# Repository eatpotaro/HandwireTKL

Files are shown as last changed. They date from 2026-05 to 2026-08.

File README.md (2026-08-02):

# Handwiring a TKL Keyboard to replace my old one!
see project on macondo here   
(https://macondo.hackclub.com/projects/15845)

# Features
Full ISO TKL Layout  
1 Rotary Encoders    
128x32 OLED Display  
No PCB needed!  

# How to use
3D print bottom plate, risers, and top plate, or case and top plate
Handwire all switches and microcontroller according to design
Install circuitpython and KMK on microcontroller by dragging .uf2 file when in boot mode   
Install the software (ball.bmp, boid.py, and main.py all in the root directory)

# Firmware Installation Instructions
Assuming you are using the CPico RP2040 as in the build, download this file  
https://circuitpython.org/board/raspberry_pi_pico/   
Then, drag the .uf2 into the microcontroller when it is in boot mode. After that install KMK from here  
https://github.com/KMKfw/kmk_firmware/archive/refs/heads/main.zip    
finally, drag in ball.bmp, boid.py, and main.py into the root directory of the microcontroller.        
See the KMK getting started guide here https://github.com/KMKfw/kmk_firmware/blob/main/docs/en/Getting_Started.md

# Firmware Build Instructions
Since this runs on KMK, there is no need to compile or build the firmware.    
Setup the device as per the README and it will work correctly 

# CAD files
This contains multiple CAD files
- 3D printed plate

- 3D printed case

- 3D printed keycaps

- Milled aluminium case


# Pictures
Layout

Wiring








# Bill of Materials
| Component | Quantity | Total Price (£) | Link |
|---|---|---|---|
| CPico RP2040 | 1 | 6.50 | https://thepihut.com/products/cpico-rp2040?variant=54040618369409 |
| Gazzew Black Boba U4 | 9 | 58.50 | https://www.mechmods.co.uk/collections/keyboard-switches/products/gazzew-black-boba-u4?variant=43956181401823 |
| Durock V3 Stabilisers | 1 set | 15.00 | https://www.mechmods.co.uk/collections/keyboard-stabilisers/products/durock-screw-in-stabilisers-v3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 |
| 20-pin 0.1" Female Header (White, 5-pack) | 1 | 2.20 | https://thepihut.com/products/20-pin-0-1-female-header-white-5-pack?variant=19932895346750 |
| Short Plug Headers for Raspberry Pi Pico (2 × 20 Pin Male) | 1 | 1.00 | https://thepihut.com/products/short-plug-headers-for-raspberry-pi-pico-2-x-20-pin-male |
| TH Diode 1N4148TR | 85 | 2.55 | https://mechboards.co.uk/products/kit-components-and-parts?variant=55527711277436 |
| 128×32 I2C OLED Graphic Display | 1 | 4.00 | https://mechboards.co.uk/products/oled-screen?_pos=3&_sid=27145306e&_ss=r |
| 8mm M2 Screws | 24 | 0.72 | https://mechboards.co.uk/products/kit-components-and-parts?variant=55527712784764 |
| 12mm M2 Brass Standoff | 12 | 0.36 | https://mechboards.co.uk/products/kit-components-and-parts?variant=55527713014140 |
| PEC11-4215F-S24 Rotary Encoder | 1 | 4.40 | https://thepihut.com/products/rotary-encoder-extras |
| Solid Core Wire | - | - | - |
| Solder | - | - | - |
| 3D Printed Plate, Keycaps, Case | - | - | - |
| Milled Aluminium Case* | - | - | - |

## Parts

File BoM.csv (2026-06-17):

Component | Quantity | Total Price (œ) | Link
CPico RP2040 | 1 | 6.5 | https://thepihut.com/products/cpico-rp2040?variant=54040618369409
Gazzew Black Boba U4 | 9 | 58.5 | https://www.mechmods.co.uk/collections/keyboard-switches/products/gazzew-black-boba-u4?variant=43956181401823
Durock V3 Stabilisers | 1 set | 15 | https://www.mechmods.co.uk/collections/keyboard-stabilisers/products/durock-screw-in-stabilisers-v3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
20-pin 0.1" Female Header - White - 5 pack | 1 | 2.2 | https://thepihut.com/products/20-pin-0-1-female-header-white-5-pack?variant=19932895346750
Short Plug Headers for Raspberry Pi Pico - 2 x 20 Pin Male | 1 | 1 | https://thepihut.com/products/short-plug-headers-for-raspberry-pi-pico-2-x-20-pin-male
TH Diode 1N4148TR | 85 | 2.55 | https://mechboards.co.uk/products/kit-components-and-parts?variant=55527711277436
128ž32 I2C OLED graphic display | 1 | 4 | https://mechboards.co.uk/products/oled-screen?_pos=3&_sid=27145306e&_ss=r
8mm M2 Screws | 24 | 0.72 | https://mechboards.co.uk/products/kit-components-and-parts?variant=55527712784764
12mm M2 Brass Standoff | 12 | 0.36 | https://mechboards.co.uk/products/kit-components-and-parts?variant=55527713014140
PEC11-4215F-S24 Rotary Encoder | 1 | 4.4 | https://thepihut.com/products/rotary-encoder-extras
Solid Core Wire | - | - | -
Solder | - | - | -
3D Printed Plate, Keycaps, Case | - | - | -
Milled Aluminium Case* | - | - | -

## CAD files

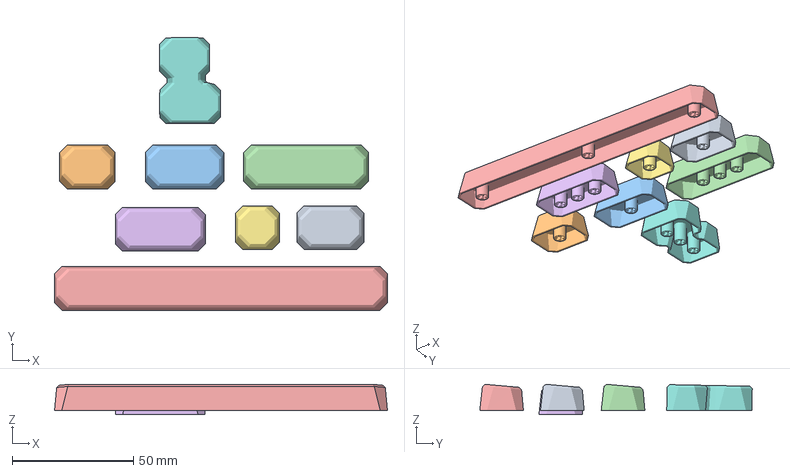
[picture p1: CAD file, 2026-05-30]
3DModel/allKeycaps.3mf
137.1 x 112.2 x 12.5 mm
keycap (1) x 3
keycap (2) x 2
keycap (3) (11)
keycap
keycap

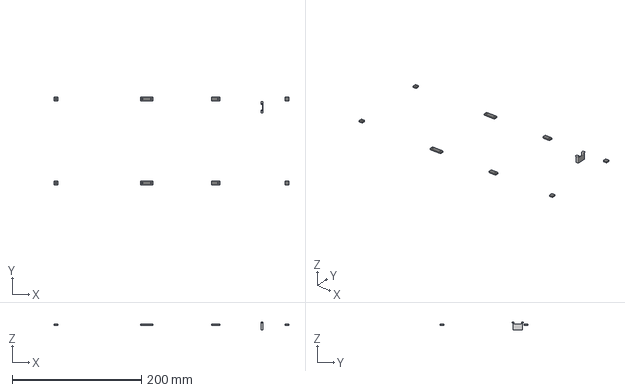
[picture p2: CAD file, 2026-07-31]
3DModel/Step/Risers.step
363.2 x 135.7 x 12.0 mm

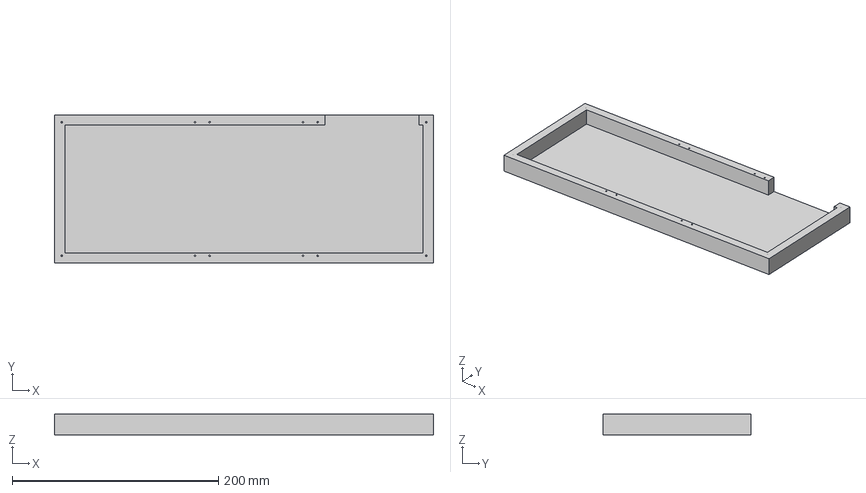
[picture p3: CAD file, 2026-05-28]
3DModel/AluCase.3mf
367.7 x 143.8 x 20.0 mm

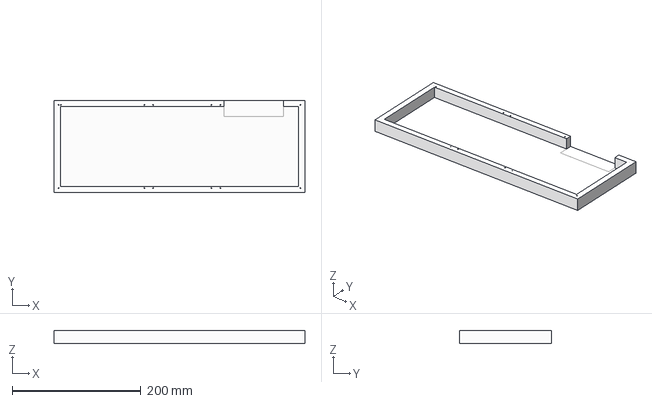
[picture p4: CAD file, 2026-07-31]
3DModel/Step/Case.step
390.4 x 143.8 x 20.0 mm

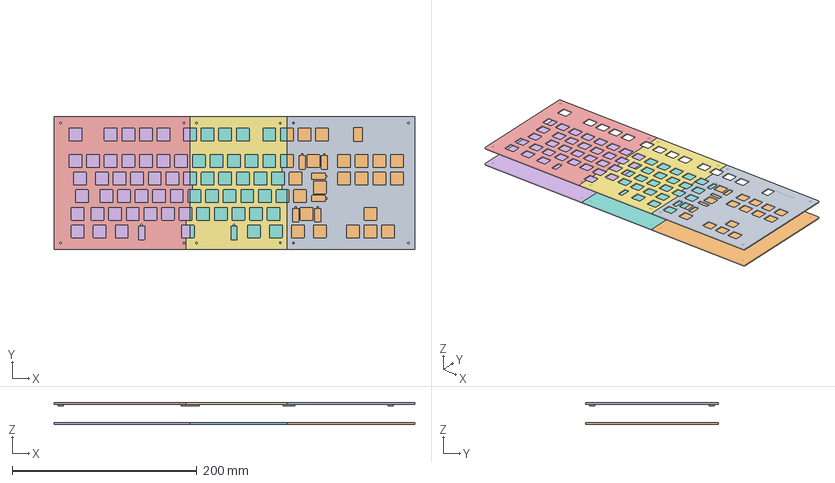
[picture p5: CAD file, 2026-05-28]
3DModel/3DPrintPlateCase.3mf
390.4 x 143.8 x 24.0 mm
corner1
corner2
corner3
corner4
left
leftbottom
middle
middlebottom
right
rightbottom
riser1
riser2
riser3
riser4

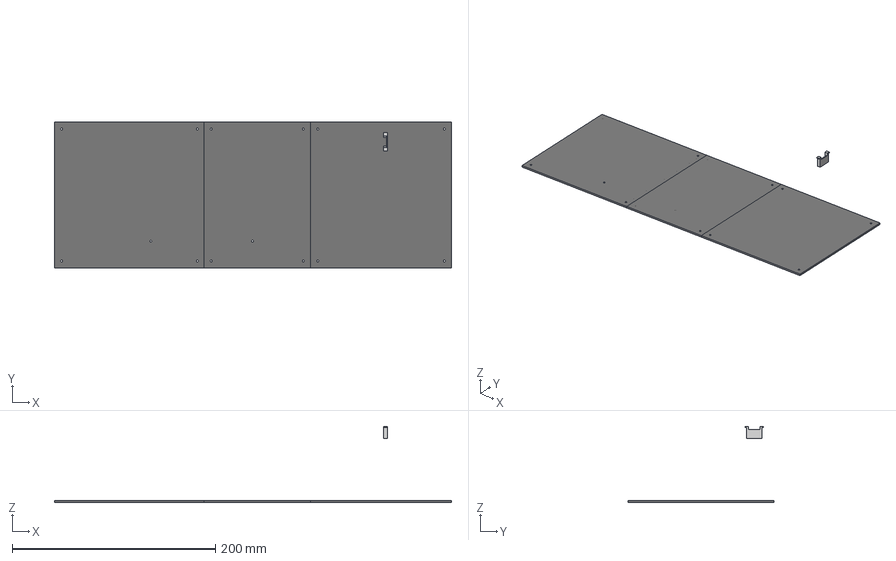
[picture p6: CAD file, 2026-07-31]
3DModel/Step/BottomPlate.step
390.4 x 143.8 x 75.0 mm

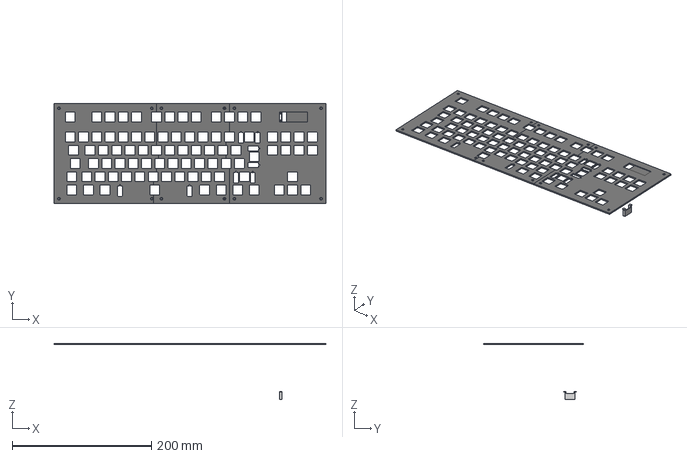
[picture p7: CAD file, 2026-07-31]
3DModel/Step/Plate.step
390.4 x 143.8 x 81.0 mm

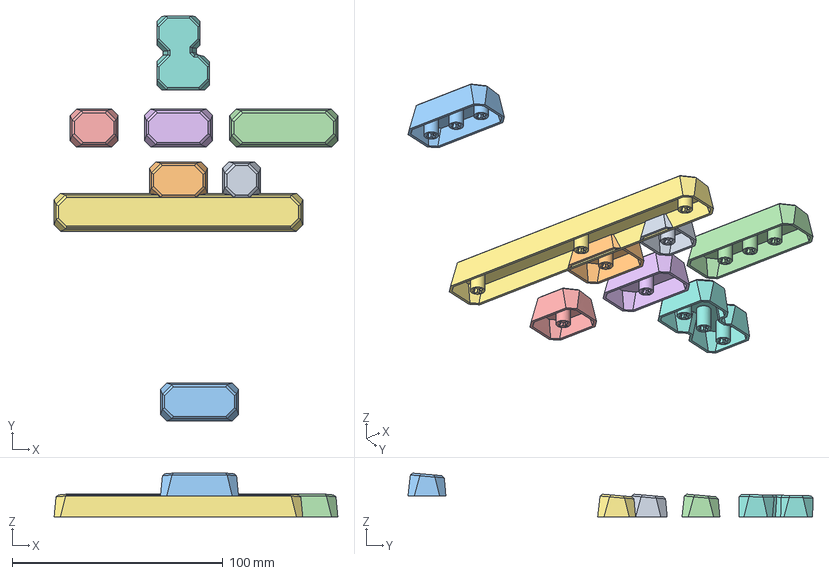
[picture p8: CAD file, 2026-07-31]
3DModel/Step/Keycaps.step
134.7 x 192.2 x 20.8 mm
1Key
1.5key
2key
1.25key
1.75key
6.25key
iso

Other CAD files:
3DModel/AluCase.stl
3DModel/FusionProjectAllParts.f3d

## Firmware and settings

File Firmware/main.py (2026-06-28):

#show starting of device
print("Hello World!")

#import libraries
import board

from kmk.kmk_keyboard import KMKKeyboard
from kmk.keys import KC
from kmk.scanners import DiodeOrientation
from kmk.keys import Key

from kmk.modules.layers import Layers

from kmk.extensions.international import International
from kmk.modules.encoder import EncoderHandler
from kmk.extensions.media_keys import MediaKeys

import board
import busio

import random

from kmk.extensions.display import Display, TextEntry, ImageEntry

from boid import Ball, Boid

#for display from example
# For SSD1306
from kmk.extensions.display.ssd1306 import SSD1306

# Replace SCL and SDA according to your hardware configuration.
i2c_bus = busio.I2C(board.GP1, board.GP0)

driver = SSD1306(
    # Mandatory:
    i2c=i2c_bus,
)

# setup a new keyboard object with an updateloop
class UpdateKeyboard(KMKKeyboard):
    def __init__(self) -> None:
        super().__init__()
        
    def _main_loop(self) -> None:
        super()._main_loop()
        updateDisplay()
        
keyboard = UpdateKeyboard()

#add extras
keyboard.extensions.append(International())
keyboard.extensions.append(MediaKeys())
layers = Layers()
keyboard.modules.append(layers)

#setup encoder
encoder_handler = EncoderHandler()
encoder_handler.pins = ((board.GP27, board.GP28, None, False, 4),)
encoder_handler.map = [ ((KC.VOLD, KC.VOLU, KC.NO),), ]
keyboard.modules.append(encoder_handler)

#setup keymap
keyboard.col_pins = (board.GP8,board.GP9,board.GP10,board.GP11,board.GP12,board.GP13,board.GP14,board.GP15,board.GP16,board.GP17,board.GP18,board.GP19,board.GP20,board.GP21,board.GP22,board.GP26,)
keyboard.row_pins = (board.GP2,board.GP3,board.GP4,board.GP5,board.GP6,board.GP7,)
keyboard.diode_orientation = DiodeOrientation.ROW2COL

#setup readers so can call change states based on keypressed e.g. capslock
isCaps = False
    
class CapsReader(Key):
    def on_press(self, key: Key, is_pressed: bool):
        global isCaps
        isCaps = not isCaps

KC.CAPS = CapsReader()

keyboard.keymap = [[
KC.LCTL, KC.LGUI, KC.LALT, KC.NO, KC.NO, KC.NO,KC.SPC, KC.NO, KC.NO, KC.NO, KC.RALT, KC.MO(2),KC.MO(2), KC.RCTL, KC.LEFT, KC.DOWN,
KC.LSFT, KC.NONUS_BSLASH, KC.Z, KC.X, KC.C, KC.V,KC.B, KC.N, KC.M, KC.COMM, KC.DOT, KC.SLSH,KC.RSFT, KC.NO, KC.UP, KC.RIGHT,
KC.CAPS, KC.A, KC.S, KC.D, KC.F, KC.G,KC.H, KC.J, KC.K, KC.L, KC.SCLN, KC.QUOT,KC.NONUS_HASH, KC.ENT, KC.END, KC.NO,
KC.TAB, KC.Q, KC.W, KC.E, KC.R, KC.T,KC.Y, KC.U, KC.I, KC.O, KC.P, KC.LBRC,KC.RBRC, KC.NO, KC.DEL, KC.PGDN,
KC.GRV, KC.N1, KC.N2, KC.N3, KC.N4, KC.N5,KC.N6, KC.N7, KC.N8, KC.N9, KC.N0, KC.MINS,KC.EQL, KC.BSPC, KC.HOME, KC.PGUP,
KC.ESC, KC.F1, KC.F2, KC.F3, KC.F4, KC.F5,KC.F6, KC.F7, KC.F8, KC.F9, KC.F10, KC.F11,KC.F12, KC.NO, KC.INS, KC.PGUP, 
]]

#setup display       
# For all display types
display = Display(
    # Mandatory:
    display=driver,
    # Optional:
    width=128, # screen size
    height=32, # screen size
    flip = False, # flips your display content
    flip_left = False, # flips your display content on left side split
    flip_right = False, # flips your display content on right side split
    brightness=0.8, # initial screen brightness level
    brightness_step=0.1, # used for brightness increase/decrease keycodes
    dim_time=200, # time in seconds to reduce screen brightness
    dim_target=0.1, # set level for brightness decrease
    off_time=600, # time in seconds to turn off screen
    powersave_dim_time=10, # time in seconds to reduce screen brightness
    powersave_dim_target=0.1, # set level for brightness decrease
    powersave_off_time=30, # time in seconds to turn off screen
)

#create list of boids
boids = [Boid(64, 16, 1.2, i/2, True) for i in range(0, 12)]
#boids = [Boid(50, 10, 0.1, 0), Boid(50, 20, 0.1, 0)]

def updateDisplay():
    global display, boids
    
    for boid in boids:
        boid.updatePos(boids)
    
    if(isCaps):                                                                                                                                                                                                                    
        display.entries = [TextEntry(text="CAPS ON!", x=0, y=0),]
    else:
        if(len(display.entries) != len(boids)):
            display.entries = []
            for boid in boids:
                display.entries.append(ImageEntry(image="ball.bmp", x=boid.getXPosInt(), y=boid.getYPosInt()),)
                
        for i in range(len(boids)):
            display.entries[i].x = int(boids[i].getXPosInt())
            display.entries[i].y = int(boids[i].getYPosInt())
            
    display.render(keyboard.active_layers[-1])

keyboard.extensions.append(display)

if __name__ == '__main__':
    keyboard.go()

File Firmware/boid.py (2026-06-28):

import math

def getMag(xpos, ypos):
    return (xpos ** 2 + ypos ** 2)**0.5

#setup ball class for display
class Ball():        
    def __init__(self, xpos, ypos, vel, angle, isWrap = True):
        self.xpos = xpos
        self.ypos = ypos
        self.vel = vel
        self.angle = angle
        self.isWrap = isWrap
        
    def updatePos(self):
        self.moveBall()
        if self.isWrap:
            self.wrapPos()
        else:
            self.clampPos()
        
    def getXYVel(self):
        #return x, then y components of velocity
        return math.cos(self.angle) * self.vel, math.sin(self.angle) * self.vel
        
    def moveBall(self):
        newVel = self.getXYVel()
        self.xpos += newVel[0]
        self.ypos += newVel[1]

    def clampPos(self):
        if(self.xpos < 0):
            self.xpos = 0
            self.angle = math.pi - self.angle 
            
        if(self.xpos > 127):
            self.xpos = 126
            self.angle = math.pi - self.angle 
            
        if(self.ypos < 0):
            self.ypos = 0
            self.angle = (2 * math.pi) - self.angle 
            
        if(self.ypos > 31):
            self.ypos = 30
            self.angle = (2 * math.pi) - self.angle 
        
    def wrapPos(self):
        if(self.xpos < 0):
            self.xpos = 127
        if(self.xpos > 127):
            self.xpos = 0
            
        if(self.ypos < 0):
            self.ypos = 31
        if(self.ypos > 31):
            self.ypos = 0
            
    def getXPosInt(self):
        return int(self.xpos)
    
    def getYPosInt(self):
        return int(self.ypos)

    def distSquared(self, ball):
        return (self.xpos - ball.xpos) ** 2 + (self.ypos - ball.ypos) ** 2

    def angleBetween(self, ball):
        btoax, btoay =  self.xpos - ball.xpos, self.ypos - ball.ypos
        
        return math.atan2(btoay, btoax)
    
    def angleTo(self, xpos, ypos):
        atobx, atoby =  xpos - self.xpos, ypos - self.ypos
        
        return math.atan2(atoby, atobx)
        

class Boid(Ball):    
    def __init__(self, xpos, ypos, vel, angle, isWrap = True):
        super().__init__(xpos, ypos, vel, angle, isWrap)
    
    #extent updatepos to update velocity as well
    def updatePos(self, boids):
        super().updatePos()
        self.updateVel(boids)
        
    def updateVel(self, boids):
        closeboids = []
        for boid in boids:
            if(boid == self):
                continue
            if(self.distSquared(boid) > 2000):
                continue
            closeboids.append(boid)
                
        
        sx, sy = self.seperation(closeboids)
        ax, ay = self.alignment(closeboids)
        cx, cy = self.cohesion(closeboids)
        
        xtotal = sx * 1.6 + ax + cx
        ytotal = sy * 1.6 + ay + cy
        
        targetangle = math.atan2(ytotal, xtotal)
        rotdir = 1
        diff = (targetangle - self.angle + math.pi) % (2 * math.pi) - math.pi
        maxrot = self.vel / 6
        if(diff < 0):
            rotdir = -1
        if(abs(diff) > maxrot):
            self.angle += maxrot * rotdir
        else:
            self.angle = targetangle
        
    def seperation(self, boids):
        #stay at least a certain distance from another boid
        #do this by finding the closest boid and returning the opposite direction
        if(len(boids) == 0):
            return [math.cos(self.angle), math.sin(self.angle)]
        
        closest = None
        dist = 999999
        for boid in boids:
            newdist = self.distSquared(boid)
            if(newdist < dist):
                dist = newdist
                closest = boid
                
        angle = self.angleBetween(closest)
        return [math.cos(angle), math.sin(angle)]

    def alignment(self, boids):
        if(len(boids) == 0):
            return [math.cos(self.angle), math.sin(self.angle)]
        
        angle = 0
        for boid in boids:
            angle += boid.angle
        angle /= len(boids)
        return [math.cos(angle), math.sin(angle)]
    
    def cohesion(self, boids):
        #try to aim towards the center of the flock of boids
        centerx, centery = 0, 0
        if(len(boids) == 0):
            return [math.cos(self.angle), math.sin(self.angle)]
        
        for boid in boids:
            centerx += boid.xpos
            centery += boid.ypos
        centerx /= len(boids)
        centery /= len(boids)
        
        angle = self.angleTo(centerx, centery)
        return [math.cos(angle), math.sin(angle)]
        
        
        
        
        
        
        

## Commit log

2026-05-28 add 3d print files, case files, wiring files, BoM
    [3DPrintPlateCase.3mf, AluCase.3mf, AluCase.stl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]
2026-05-30 add keycap files
    [allKeycaps.3mf]
2026-06-17 added redundant bom to the readmy
2026-06-17 added redundant bom to the readme (table)
2026-06-17 add new wiring files
    [HandwireTKL.kicad_pcb, HandwireTKL.kicad_sch]
2026-07-31 added step files
    [BottomPlate.step, Case.step, Keycaps.step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]
